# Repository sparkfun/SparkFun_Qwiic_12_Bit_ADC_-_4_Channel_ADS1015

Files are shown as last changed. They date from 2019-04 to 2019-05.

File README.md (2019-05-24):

SparkFun Qwiic ADC
========================================

SparkFun Qwiic 12 Bit ADC - 4 Channel ADS1015

[*SparkFun Qwiic 12 Bit ADC - 4 Channel ADS1015 (Sen-15334)*](https://www.sparkfun.com/products/15334)

Qwiic breakout board for the ADS1015 4-channel 12-bit ADC from TI.

A lot of the time you just need to add more analog inputs to solve a problem. It happens. The SparkFun Qwiic 12 Bit ADC can provide four channels of I2C controlled ADC input to your Qwiic enabled project. These channels can be used as single-ended inputs, or in pairs for differential inputs. What makes this even more powerful is that it has a programmable gain amplifier that lets you "zoom in" on a very small change in analog voltage (but will still effect your input range and resolution). Utilizing our handy Qwiic system, no soldering is required to connect it to the rest of your system. However, we still have broken out 0.1"-spaced pins in case you prefer to use a breadboard.

The ADS1015 uses its own internal voltage reference for measurements, but a ground and 3.3V reference are also available on the pin outs for users. This ADC board includes screw pin terminals on the four channels of input, allowing for solderless connection to voltage sources in your setup. It also has an address jumper that lets you choose one of four unique addresses (0x48, 0x49, 0x4A, 0x4B). With this, you can connect up to four of these on the same I2C bus and have sixteen channels of ADC. The maximum resolution of the converter is 12-bits in differential mode and 11-bits for single-ended inputs. Step sizes range from 125μV per count to 3mV per count depending on the full-scale range (FSR) setting.

We have included an onboard 10K trimpot connected to channel A3. This is handy for initial setup testing and can be used as a simple variable input to your project. But don't worry, we added an isolation jumper so you can use channel A3 however you'd like.

Repository Contents
-------------------

* **/Hardware** - Eagle design files (.brd, .sch)
* **/Production** - Production panel files (.brd)

Documentation
--------------
* **[Arduino Library for the ADS1015](https://github.com/sparkfun/SparkFun_ADS1015_Arduino_Library)** - Arduino library for the ADS1015.
* **[Hookup Guide](https://learn.sparkfun.com/tutorials/qwiic-12-bit-adc-hookup-guide)** - Basic hookup guide for the SparkFun Qwiic 12 Bit ADC - 4 Channel ADS1015. Includes hardware overview, software installation instructions and overviews of each example in the arduino library.

License Information
-------------------

This product is _**open source**_! 

Please review the LICENSE.md file for license information. 

If you have any questions or concerns on licensing, please visit the [SparkFun Forum](https://forum.sparkfun.com/index.php) and post a topic. For more general questions related to our qwiic system, please visit this section of the forum: [SparkFun Forums: QWIIC SYSTEMS](https://forum.sparkfun.com/viewforum.php?f=105)

Distributed as-is; no warranty is given.

- Your friends at SparkFun.

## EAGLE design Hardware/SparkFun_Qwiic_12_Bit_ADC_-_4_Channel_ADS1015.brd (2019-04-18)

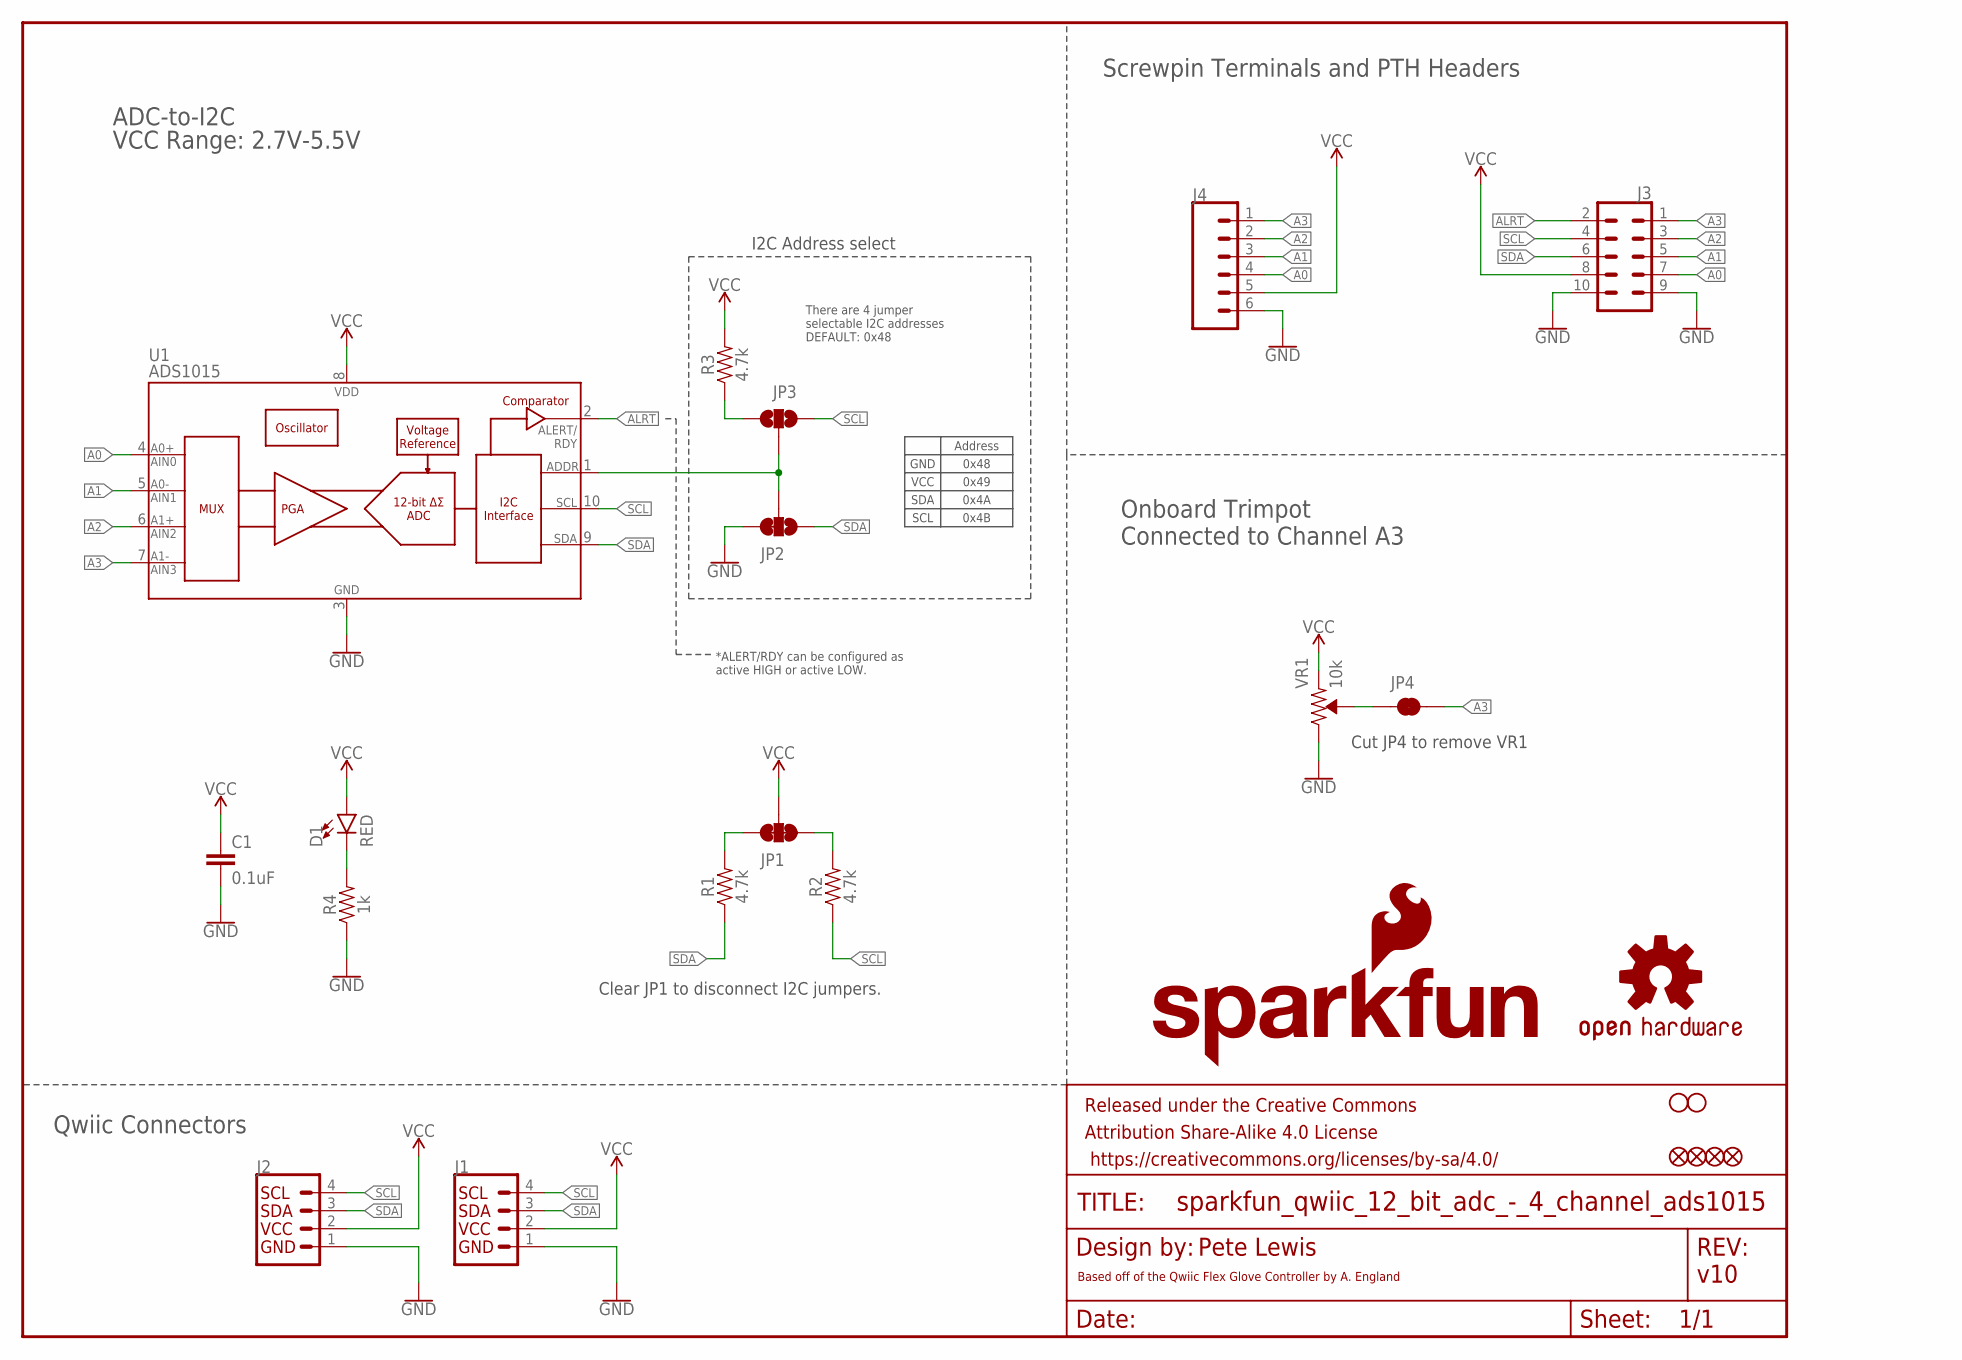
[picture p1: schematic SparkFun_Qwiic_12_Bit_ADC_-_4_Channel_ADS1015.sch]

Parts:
C1: 0.1uF; 0603
D1: RED; LED-0603
FD1, FD2, FD3, FD4: FIDUCIALUFIDUCIAL; FIDUCIAL-MICRO
FRAME1: FRAME-LETTER; CREATIVE_COMMONS
H1, H2: STAND-OFF
J1, J2: QWIIC_CONNECTORJS-1MM; JST04_1MM_RA
J3: CONN_05X2NO_SILK; 2X5_NOSILK
J4: Screw Pin; SCREWTERMINAL-3.5MM-6
JP1: JUMPER-SMT_3_2-NC_TRACE_NO-SILK; SMT-JUMPER_3_2-NC_TRACE_NO-SILK
JP2: JUMPER-SMT_3_1-NC_TRACE_NO-SILK; SMT-JUMPER_3_1-NC_TRACE_NO-SILK
JP3: JUMPER-SMT_3_NO_NO_SILK; SMT-JUMPER_3_0-NO_TRACE_NO-SILK
JP4: JUMPER-SMT_2_NC_TRACE_SILK; SMT-JUMPER_2_NC_TRACE_SILK
LOGO1: SFE_LOGO_NAME.1_INCH; SFE_LOGO_NAME_.1
LOGO2: OSHW-LOGOS; OSHW-LOGO-S
LOGO3: SFE_LOGO_FLAME.1_INCH; SFE_LOGO_FLAME_.1
R1, R2, R3: 4.7k; 0603
R4: 1k; 0603
U1: ADS1015; MSOP10
VR1: 10k; TRIMPOT-SMD-3MM-CLOSED

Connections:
A0: J3.7, J4.4, U1.4 (AIN0)
A1: J3.5, J4.3, U1.5 (AIN1)
A2: J3.3, J4.2, U1.6 (AIN2)
A3: J3.1, J4.1, JP4.2, U1.7 (AIN3)
ADDR: JP2.2, JP3.2, U1.1 (ADDR)
ALRT: J3.2, U1.2 (ALERT/RDY)
GND: C1.2, J1.1, J2.1, J3.9, J3.10, J4.6, JP2.3, R4.1, U1.3 (VSS), VR1.3 (CW)
unnamed: JP4.1, VR1.2 (WIPER)
unnamed: D1.C, R4.2
unnamed: JP3.1, R3.1
unnamed: JP1.1, R2.2
unnamed: JP1.3, R1.2
SCL: J1.4, J2.4, J3.4, JP3.3, R2.1, U1.10 (SCL)
SDA: J1.3, J2.3, J3.6, JP2.1, R1.1, U1.9 (SDA)
VCC: C1.1, D1.A, J1.2, J2.2, J3.8, J4.5, JP1.2, R3.2, U1.8 (VDD), VR1.1 (CCW)

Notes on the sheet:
v10
Qwiic Connectors
ADC-to-I2C
Pete Lewis
There are 4 jumper selectable I2C addresses DEFAULT: 0x48
Address
0x48
0x49
0x4A
0x4B
GND
VCC
SDA
SCL
VCC Range: 2.7V-5.5V
Clear JP1 to disconnect I2C jumpers.
Based off of the Qwiic Flex Glove Controller by A. England
Onboard Trimpot Connected to Channel A3
Cut JP4 to remove VR1
I2C Address select
Screwpin Terminals and PTH Headers
*ALERT/RDY can be configured as active HIGH or active LOW.

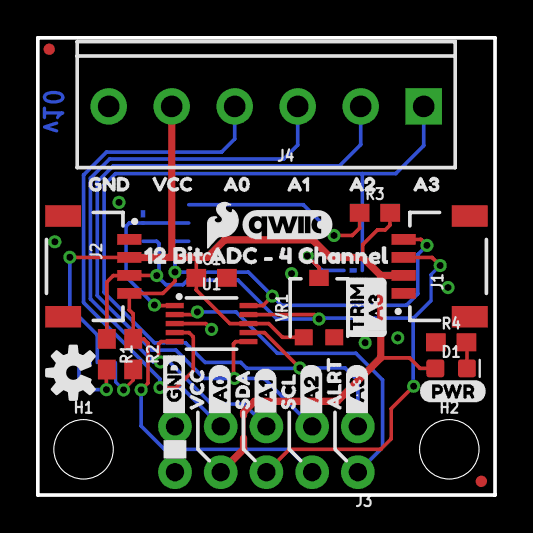
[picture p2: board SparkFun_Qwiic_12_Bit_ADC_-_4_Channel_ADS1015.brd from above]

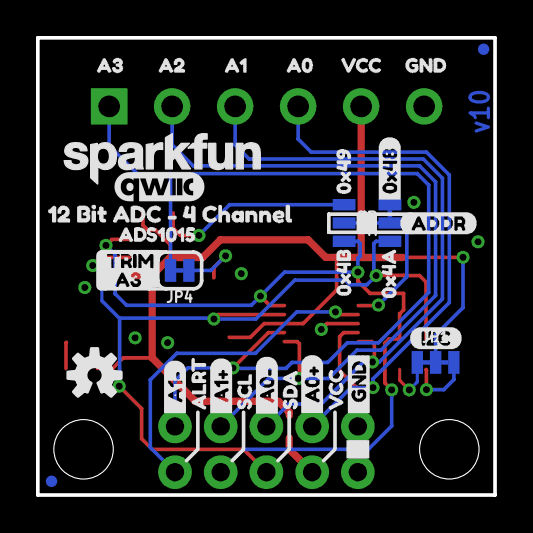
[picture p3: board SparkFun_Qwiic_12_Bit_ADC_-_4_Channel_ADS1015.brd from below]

Board: 2 copper layers, 25.4 x 25.4 mm, 73 parts (34 on the bottom side), 15 nets.

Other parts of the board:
U$1, U$18, U$30, U$34: VCC1
U$2, U$35: GND0
U$3: 0X4A2
U$4: 0X491
U$5, U$36: A02
U$6, U$37: A13
U$7, U$38: A24
U$8, U$39: A35
U$9: _A0#3
U$10: _A0#4
U$11, U$19: TRIM7
U$12: 0X4B3
U$13: OSHW-LOGO-S
U$14: _A1#5
U$15: _A1#6
U$16, U$43: 12_BIT_ADC_#_4_CHANNEL1
U$17, U$22: _A3_0
U$20, U$29: _GND17
U$21, U$31: SDA6
U$23, U$32: SCL7
U$24, U$33: ALRT8
U$25: _A013
U$26: _A114
U$27: _A215
U$28: _A316
U$40: PWR0
U$41: I2C1
U$42: 0X480
U$44, U$47: QWIIC_5MM
U$45: ADDR0
U$46: ADS10150

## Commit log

2019-04-15 Initial proto layout
    [Qwiic_ADC_ADS1015.brd, Qwiic_ADC_ADS1015.sch]
2019-04-16 Hardware changes - pre-group review
    JP4 label changed to TRIM A0, also labeled trimpot on tops the same.
    Product name on bottom silk.
    Flipped pin order to have GND on left side of standard I2C pinout.
    Bottom labels now show differential inputs names (A0+, A0-, etc.)
    Added power LED, moved OSHW logo to bottom silk.
    [Qwiic_ADC_ADS1015.brd, Qwiic_ADC_ADS1015.sch]
2019-04-16 updated product name silk
    [Qwiic_ADC_ADS1015.brd, Qwiic_ADC_ADS1015.sch]
2019-04-16 ADDR label on jumper silk on bottom silk
    [Qwiic_ADC_ADS1015.brd]
2019-04-16 Group design review changes
    Moved Trimpot to A3 - so that initial use case can use A0 "as usual".
    Improved address jumper labeling
    [Qwiic_ADC_ADS1015.brd, Qwiic_ADC_ADS1015.sch]
2019-04-17 Checklist changes pre double-check
    Cleaned up schematic.
    Added note for alert ready active high or low.
    Adjusted some small stuff for better ground pour flow.
    Added SS path on layer 47.
    [Qwiic_ADC_ADS1015.brd, Qwiic_ADC_ADS1015.sch]
2019-04-18 updates post double-check - vias, measures, stubs
    1- nudged vias away from being under some silk
    2- added measures for distance between standoffs
    3- removed wire stubs.
    4-moved version in bottom copper to be clear of screw pin terminal bottom silk labels.
    [Qwiic_ADC_ADS1015.brd]
2019-05-22 renaming eagle files to match github repo and product name
    [SparkFun_Qwiic_12_Bit_ADC_-_4_Channel_ADS1015.brd, SparkFun_Qwiic_12_Bit_ADC_-_4_Channel_ADS1015.sch]
2019-05-22 changed size of name text object to fit inside the schematic fram info box
    [SparkFun_Qwiic_12_Bit_ADC_-_4_Channel_ADS1015.sch]

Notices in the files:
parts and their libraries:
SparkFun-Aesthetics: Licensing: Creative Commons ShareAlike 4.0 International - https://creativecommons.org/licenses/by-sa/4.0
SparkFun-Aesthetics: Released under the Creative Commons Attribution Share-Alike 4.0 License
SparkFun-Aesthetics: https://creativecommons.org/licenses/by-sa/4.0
